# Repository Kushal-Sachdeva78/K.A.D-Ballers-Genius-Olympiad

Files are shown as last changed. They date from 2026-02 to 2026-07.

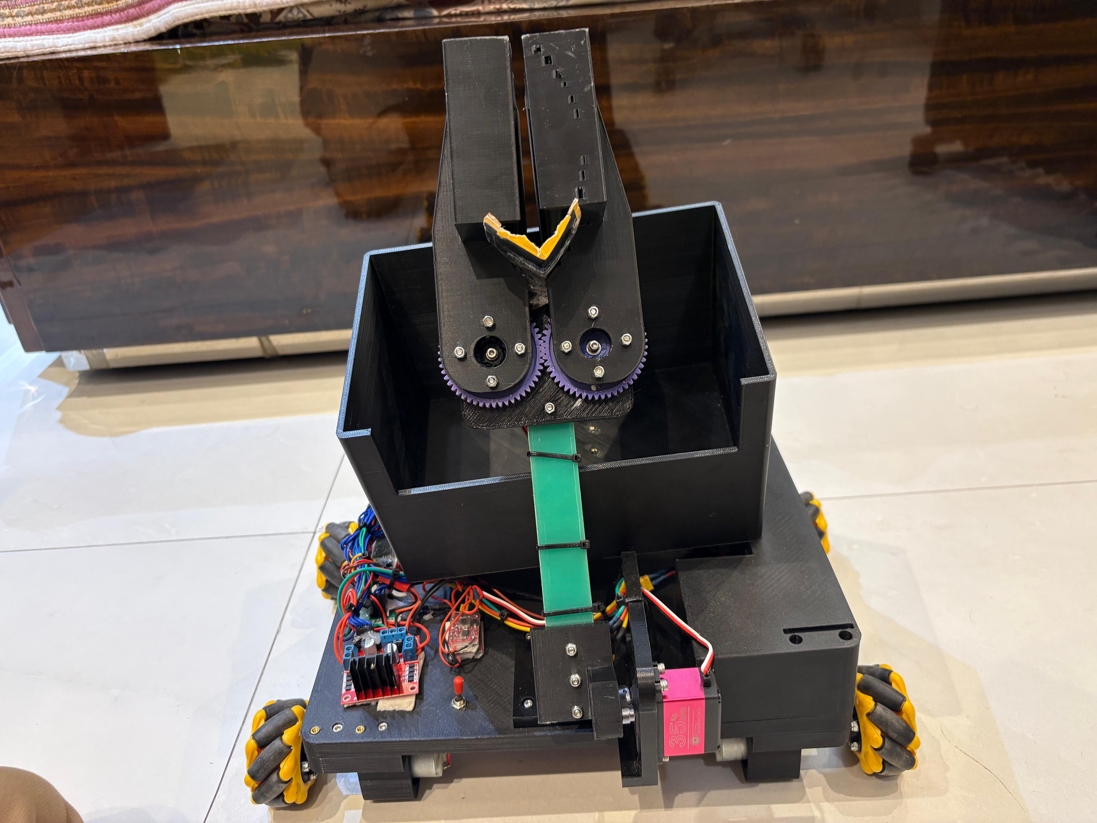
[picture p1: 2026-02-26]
Photos/Robot Image 1.jpeg

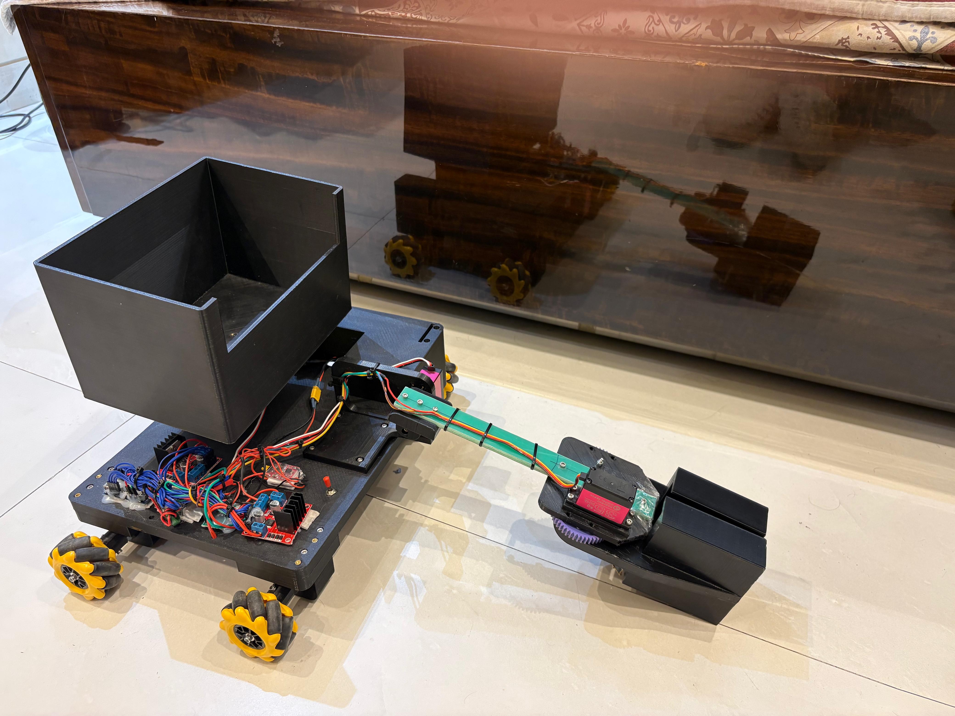
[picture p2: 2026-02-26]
Photos/Robot Image 8.jpeg

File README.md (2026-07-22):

# K.A.D Ballers: Genie Firefighter Robot

A tele-operated, four-wheel mecanum robot built by Team K.A.D Ballers for the GENIUS Olympiad robotics competition (GENIUS Robotics, Genie Firefighter 2026 game). The robot's chassis and mechanical parts are fully 3D printed in PETG, and it is driven over Bluetooth, using a three-servo manipulator to clear debris and place water gel cubes in the game's fire zone.





## Result

This project qualified as a GENIUS Olympiad finalist. The team did not attend the final round due to prior commitments.

## Team

- **Team name**: K.A.D Ballers
- **Members**: Kushal Sachdeva, Darsh Goel, Aaryan Singhania
- **School**: Vasant Valley School, Delhi, India

## Submission video

Official application video: [GENIUS Robotics_2026_KAD_Ballers on YouTube](https://youtu.be/bjkdxhQIA2E?si=Tjy7cpMIQIa94cFR)

## Robot overview

The Genie Firefighter game requires removing debris (tennis balls) from the safe zone into a debris bin, and collecting water gel cubes from the shared warehouse to place into the fire zone. Our robot handles both tasks with:

- **Mecanum drive**: four mecanum wheels for forward, backward, strafe, diagonal, and rotation movement. Each diagonal command drives exactly two of the four motors.
- **Three-servo manipulator**: an arm servo (smooth 1-degree stepped sweeps between down and up positions), a gripper servo (open/close), and a basket servo that flips to dump collected objects.
- **Bluetooth teleoperation**: an HC-05 module on a software serial port (9600 baud) receives single-character commands from a phone controller app.

## Hardware

| Component | Details |
| --- | --- |
| Microcontroller | Arduino Nano |
| Wireless | HC-05 Bluetooth module |
| Drive | 4x 12V 50 RPM DC motors with mecanum wheels |
| Motor drivers | 2x L298N dual H-bridge |
| Servos | 3x high-torque metal gear servos |
| Power | 12V battery with a buck converter to 5V for logic and servos |
| Chassis and parts | Fully 3D printed in PETG (SolidWorks sources and STL exports included) |

## Driver command map

| Movement | Key | Manipulator | Key |
| --- | --- | --- | --- |
| Forward / Backward | `F` / `B` | Arm up / down | `U` / `D` |
| Strafe left / right | `L` / `R` | Gripper open / close | `O` / `C` |
| Diagonals | `G` `H` `I` `J` | Basket load / unload | `M` / `N` |
| Rotate CW / CCW | `X` / `Y` | Stop | `S` |

## Repository contents

```
Code/mecanumwheelrobot/   # Arduino sketch: drive kinematics, servo control, Bluetooth command loop
3D Models/                # SolidWorks part files (.SLDPRT) with printable STL exports,
                          # plus the full assembled robot model
Photos/                   # Build, wiring, testing, and final robot photos
Docs/                     # Engineering books (Robot Design and Programming) as PDFs
```

## How to run

1. Upload `Code/mecanumwheelrobot/mecanumwheelrobot.ino` to an Arduino Nano.
2. Pair your phone with the HC-05 module.
3. Open a Bluetooth serial controller app and connect.
4. Drive and operate the manipulator with the mapped keys above.

## Related projects

Kushal and Darsh also compete as [Team VVS Ballers in RoboCupJunior Soccer](https://github.com/Kushal-Sachdeva78/VVS-Ballers-RoboCup), placing 9th at RoboCup 2026 in Incheon, South Korea.

## License

This project is licensed under the MIT License. See [LICENSE](LICENSE) for details.

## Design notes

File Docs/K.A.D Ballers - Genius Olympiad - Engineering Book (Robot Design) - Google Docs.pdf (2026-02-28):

# Engineering Book – Robot Design

## GENIUS Robotics — Genie Firefighter (2026)

Team Name: K.A.D Ballers
Team Members: Kushal Sachdeva, Darsh Goel, Aaryan Singhania School/Organization: Vasant Valley School, Delhi, India
GitHub: https://github.com/Kushal-Sachdeva78/K.A.D-Ballers-Genius-Olympiad-Robot

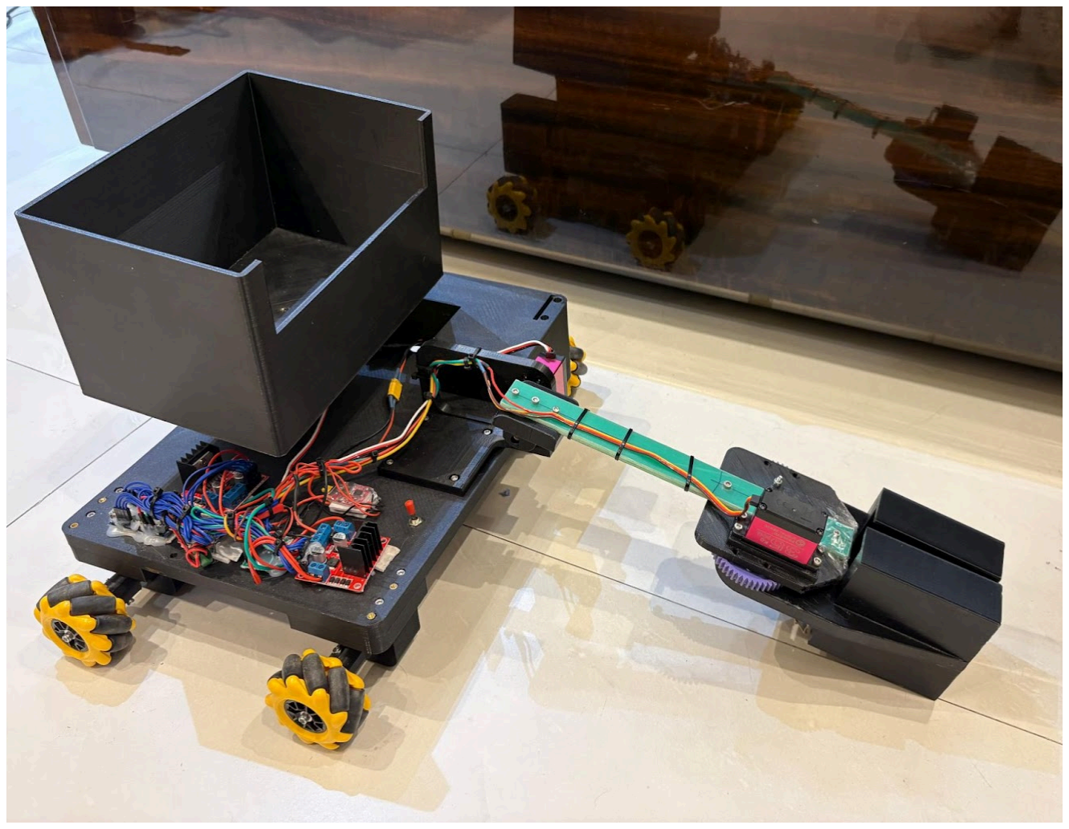
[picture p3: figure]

## 1. Executive Summary

Our Genie Firefighter robot is a tele-operated 4-mecanum drive platform designed to:

1. Clear debris (tennis balls) from the safe zone and deposit into the elevated debris bin
2. Collect water gel cubes from the shared warehouse and place them into the fire zone

The robot uses:

- 4× 12V 50 RPM DC motors for mecanum drive
- 3× metal gear 35 kg servos for arm lift, gripper open/close, and basket flip
- Arduino Nano as the main controller
- HC-05 Bluetooth module + phone app for wireless tele-op
- 2× L298N motor drivers to control the DC motors
- 12V battery + buck converter to power logic + servos

Manufacturing note: The entire robot chassis and mechanisms are 3D-printed in PETG (with metal fasteners/electronics installed).

## 2. Mission Breakdown & Constraints

### 2.1 Tasks

Task 1 (Debris):

- Collect 10 tennis balls from the safe zone
- Deposit them into the debris bin outside the field perimeter
- Safe zone must be cleared before Task 2 begins

Task 2 (Fire):

- Collect gel cubes (2.2”) from the shared warehouse
- Place/throw them into the fire zone
- Carry limit: max 5 cubes at a time
- Must not enter smoked damaged area; avoid touching buckets/houses

### 2.2 Constraints That Shaped Our Design

- Start size ≤ 20” × 20” × 20”
- Tele-op only, wireless communication only
- Onboard power only; ≤ 12V per power item
- Up to 8 DC motors allowed (we use 4)
- Accurate navigation near tape boundaries is essential (penalty avoidance)

## 3. Design Choices (Why this design)

### 3.1 Why Mecanum Drive

- Items are randomly placed → alignment speed matters
- Mecanum allows strafe + diagonal movement without turning
- Helps the driver make micro-adjustments near taped borders and around obstacles

### 3.2 Why Arm + Gripper + Basket Dump

- Tennis balls and gel cubes are different textures and shapes; a controlled grab is more reliable than pushing
- Arm + gripper gives repeatable pickup, basket provides storage, dump makes unloading faster

## 4. System Layout (Architecture)

### 4.1 Control Flow

Driver Phone (Bluetooth Serial App) → sends single character commands → HC-05 Bluetooth
→ Arduino Nano
→ outputs to:
- Motor Drivers (2× L298N) → 4 DC motors → mecanum wheels
- Servos → arm servo / gripper servo / basket servo

### 4.2 Power Distribution

- 12V battery → L298N boards → DC motors
- 12V battery → buck converter → regulated 5V rail → Arduino + HC-05 + servos
- Common ground shared across all modules for stability

## 5. Mechanical Design (Detailed)

### 5.1 Chassis & Packaging (PETG 3D Print)

Material: PETG (full robot printed)
Why PETG:
- Stronger and less brittle than PLA
- Better temperature resistance than PLA (helpful for motors/servo heat zones)
- Good layer adhesion for load-bearing parts

Chassis goals:

- Fit within starting size limits
- Keep center of gravity low (battery low, central)
- Protect electronics and wiring
- Provide rigid mounts for motors and servos (reduce flex)

Design features we included (recommended to mention during judging):

- Reinforced motor mounts (thicker walls + ribbing)
- Cable channels / tie points to prevent snagging
- Standoffs for electronics and buck converter
- Mount points that can be reprinted quickly if broken

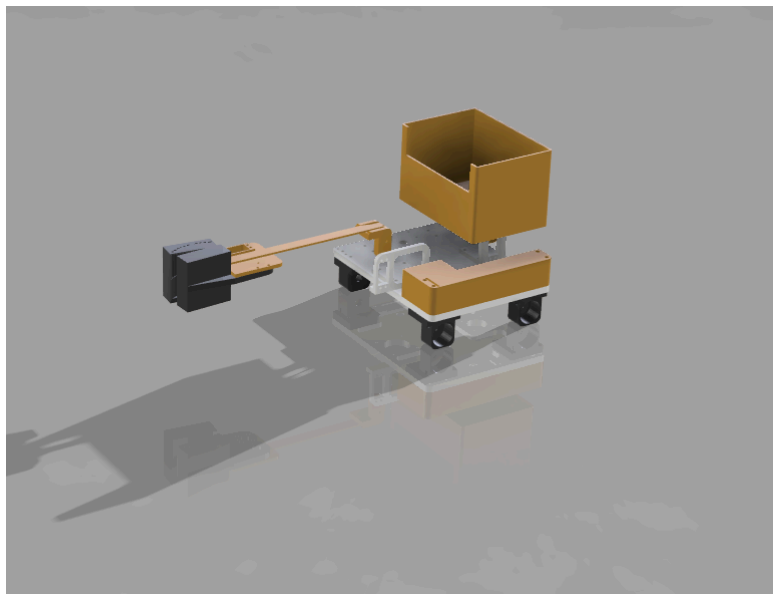
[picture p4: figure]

### 5.2 Drivetrain (4-Mecanum)

Components:

- 4 mecanum wheels
- 4× 12V 50 RPM DC motors
- 2× L298N drivers

Why it works for this game:

- Strafing reduces time spent turning
- Diagonals speed up alignment to scattered objects
- Rotation in place helps quick reorientation without overshooting taped boundaries

Build notes (PETG-specific):

- Wheel mounts printed with extra wall thickness
- Use washers/spacers to reduce wobble
- Ensure correct roller orientation (front-left/front-right must be mirrored)

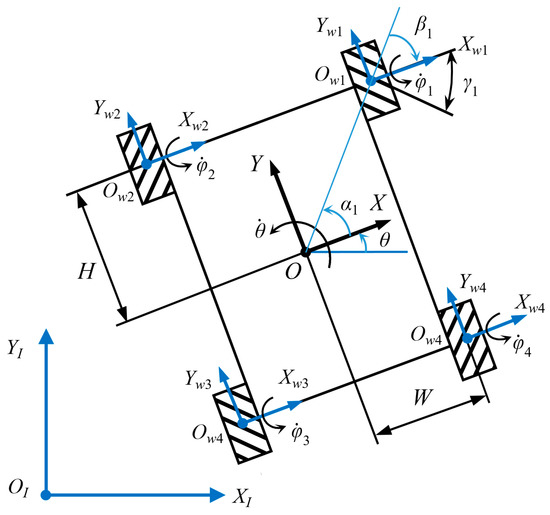
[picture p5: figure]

### 5.3 Arm Mechanism (Servo Lift)

Function: reach floor → lift to basket height Servo: 35 kg metal gear servo
Design requirements:
- Reach ground without pushing objects away
- Lift high enough to drop into basket
- Minimize flex (PETG parts reinforced)

Mechanical notes:

- Arm pivot printed thick + supported with ribs
- Servo horn mounting holes reinforced
- Endpoints tuned to avoid servo stalling at hard stops

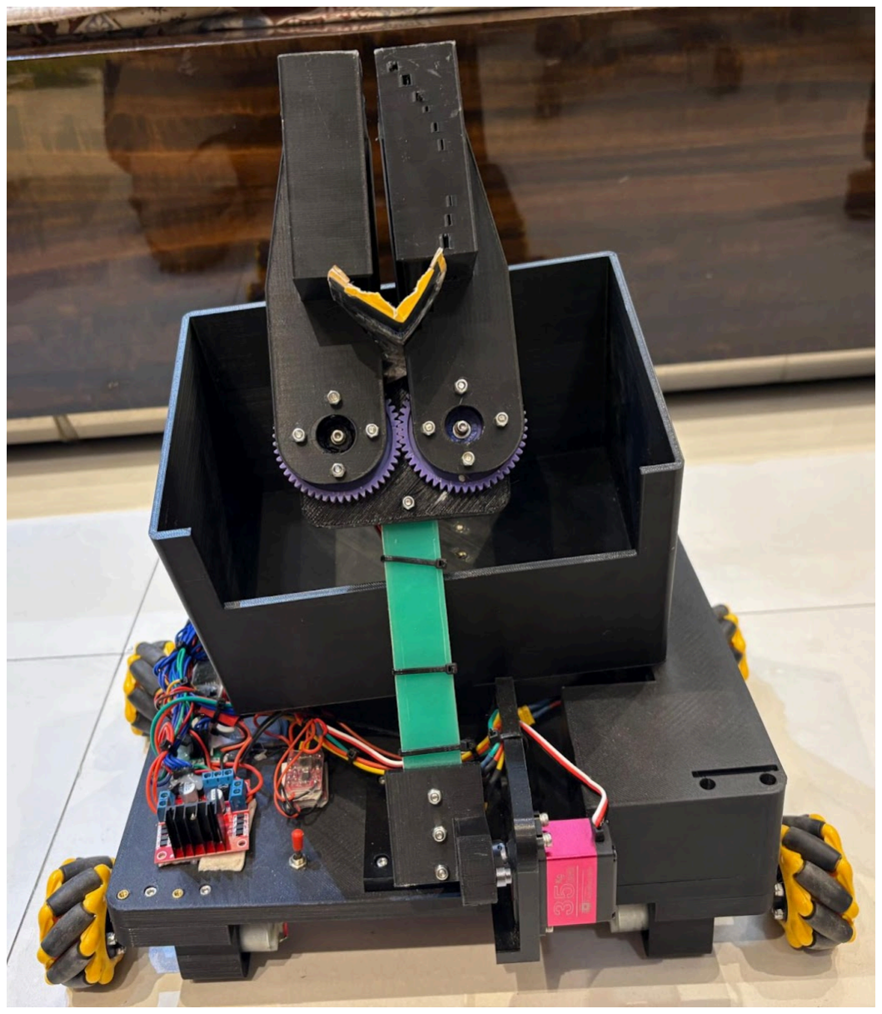
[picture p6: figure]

### 5.4 Gripper (Servo Open/Close)

Function: capture balls/cubes reliably
Servo: 35 kg metal gear servo
Design features:
- Jaw profile shaped to “cup” a tennis ball
- Closing angle tuned so gel cubes are held, not crushed
- Printed jaws reinforced at stress points (fillets/ribs)

Testing outcomes:

- Best grip happens when object is centered before closing
- Slow approach + stop command improves pickup reliability

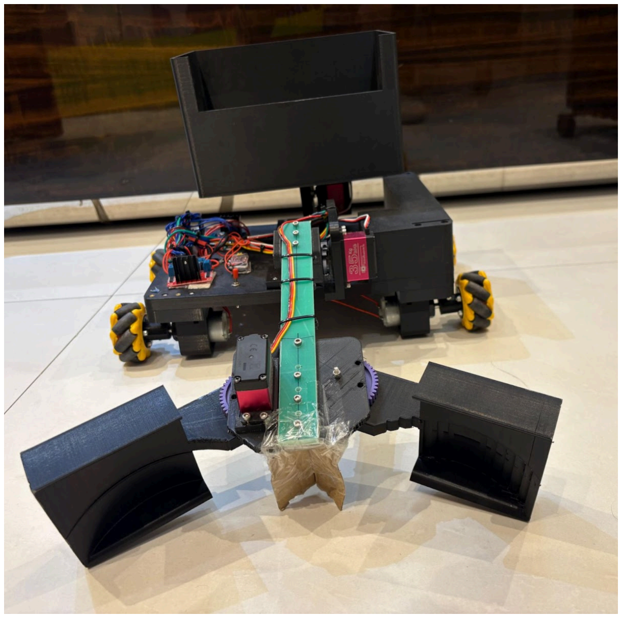
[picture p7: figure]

### 5.5 Basket / Holder + Flip Dump

Purpose:

- Store collected items (reduce trips)
- Dump quickly into debris bin / release cubes into fire zone

Mechanism:

- Basket mount hinged
- Servo moves between:
- LOAD position: holds items during driving
- UNLOAD position: flips to release

Key design constraint:

- Debris bin is elevated, so dumping angle and approach matter (future lift planned below)

## 6. Electronics Design

### 6.1 Parts Used

- Arduino Nano (main controller)
- HC-05 Bluetooth module
- 2× L298N motor driver boards
- 4× DC motors (12V, 50 RPM)
- 3× 35 kg metal gear servos
- 12V battery
- Buck converter (12V → 5V)
- Wiring, connectors, switch (recommended)

### 6.2 Electronics Layout Notes

- Keep buck converter close to Arduino/servo power distribution
- Route motor wires away from Bluetooth wires where possible
- Secure all connectors to withstand vibrations and arm motion

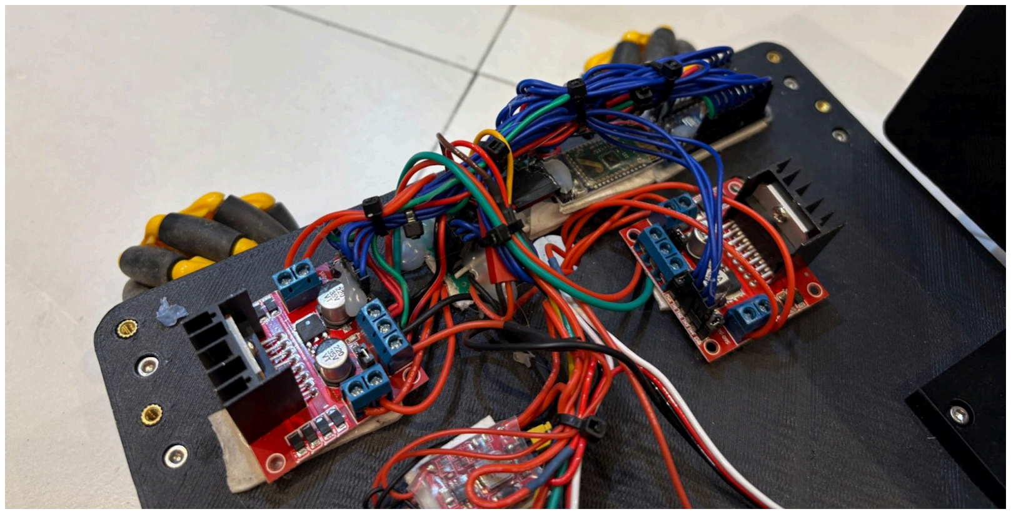
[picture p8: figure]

## 7. Coding Scheme

### 7.1 Control Method

A phone app sends single-character commands over Bluetooth to HC-05. Arduino Nano reads the character and triggers:

- mecanum movement patterns (forward/back/strafe/diagonal/rotate)
- servo position actions (arm, gripper, basket)

### 7.2 Driver Command Map (Summary)

Movement: F B L R S G H I J X Y
Servos: U/D arm, O/C gripper, M/N basket load/unload

## 8. Testing & Experiments (Development Evidence)

### 8.1 Drive Testing

- Straight driving (check drift)
- Strafing along tape line (precision)
- Rotation in place (control near boundaries)

Result: mecanum improved alignment speed significantly compared to turning-based drive.

### 8.2 Pickup Testing

- Tested tennis balls and cubes at different angles
- Tuned arm down position to prevent pushing objects away
- Tuned gripper close angle for secure hold without crushing cubes

### 8.3 Basket Testing

- Verified load position prevents spills while moving
- Verified unload position releases consistently into a target container

### 8.4 Power & Bluetooth Stability

- Tested simultaneous driving + servo movement for resets

- Verified stable control when phone is kept within close range
- Buck converter + common ground improved stability

## 9. Build Log (Recommended for Judges)

- Stage 1: CAD + first PETG chassis print (date, issues, fixes)
- Stage 2: drivetrain assembly and wheel orientation verification
- Stage 3: arm/gripper print iterations (strength improvements)
- Stage 4: electronics mounting + wiring organization
- Stage 5: integrated testing + driver training

## 10. Match Strategy

Task 1: strafe/diagonal align → arm down → grip → arm up → store → repeat → dump Task 2: warehouse entry → collect cubes (≤5) → return → place/throw into fire zone (avoid smoked zone)

Penalty prevention:

- slow down near buckets/tape
- stop before gripping
- avoid risky turns—use strafing instead

## 11. Future Implementations (Planned Upgrades)

### 11.1 Scissor Lift for Basket (Raise to Bin Height)

Problem: debris bin is elevated; dumping from low height can be inconsistent. Upgrade: add a scissor lift under the basket to raise it before unloading.

- Actuation options: lead screw + motor, linear actuator, or gear-driven lift
- Adds controlled vertical reach for consistent bin dumping

Expected benefit: faster scoring + fewer missed deposits.

### 11.2 Rubber-Band Rotating Intake (Fast Automatic Intake)

Problem: arm+gripper is reliable but slower for many items.
Upgrade: add a front rubber-band roller intake:
- two inward-spinning rollers pull balls/cubes automatically
- guides items into basket with less driver precision needed

Expected benefit: faster debris clear + faster cube collection + reduced driver workload.

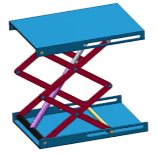
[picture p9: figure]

## 12. Bill of Materials (BOM)

Mechanical (3D Printed PETG)

- PETG filament (chassis, mounts, arm, gripper, basket, brackets)
- 4× mecanum wheels
- Fasteners: screws/nuts/washers (assorted)
- Hinges/pins for arm and basket pivots (printed or metal)

Electrical

- Arduino Nano
- HC-05 Bluetooth module
- 2× L298N motor drivers

- 4× 12V 50 RPM DC motors
- 3× 35 kg metal gear servos
- 12V battery pack
- Buck converter (12V → 5V)
- Wiring/connectors/switch/zip ties

## 13. GitHub Repository (Code + 3D Models + Photos)

All design files, code, and documentation are stored in our GitHub repository.

GitHub Repo Link:
https://github.com/Kushal-Sachdeva78/K.A.D-Ballers-Genius-Olympiad-Robot

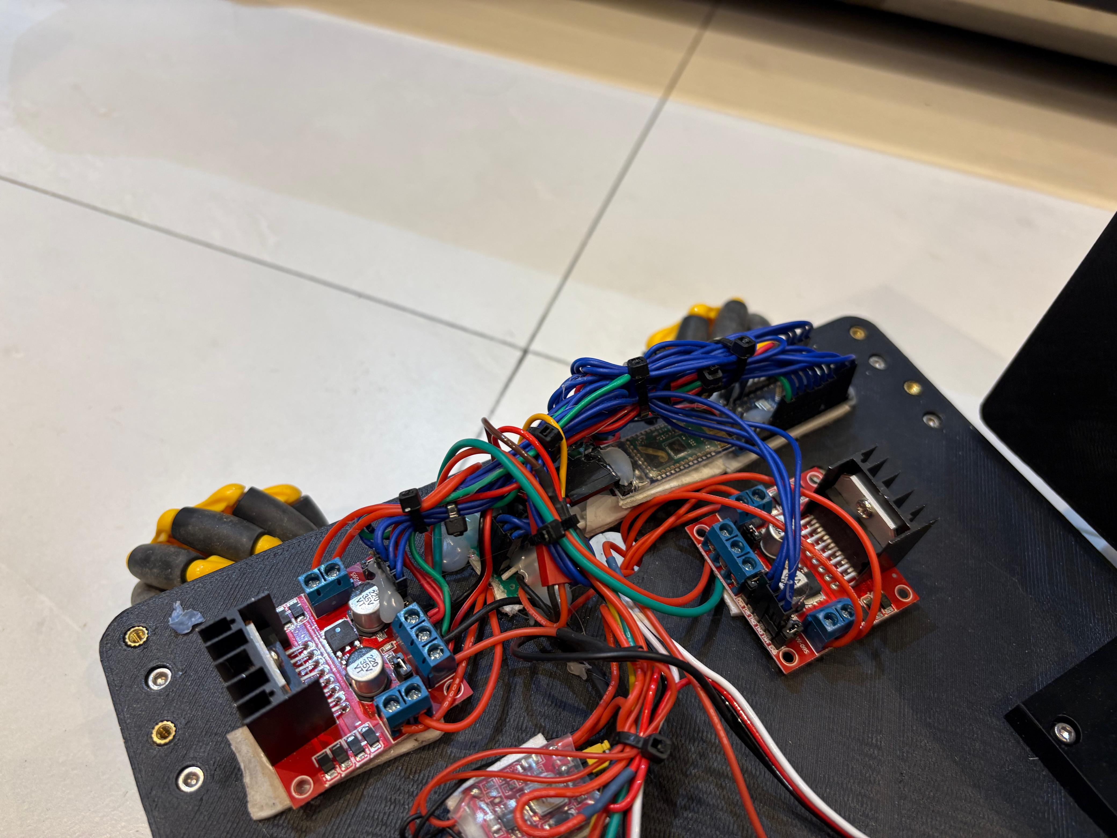
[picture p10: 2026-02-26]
Photos/Robot Image 4.jpeg

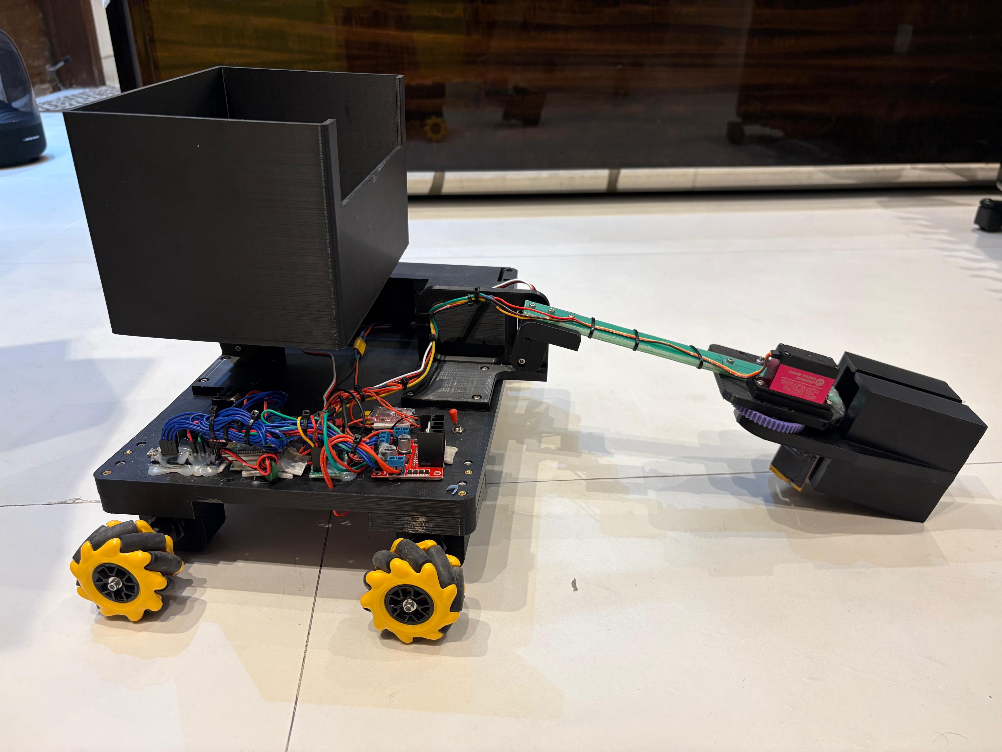
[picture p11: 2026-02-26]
Photos/Robot Image 7.jpeg

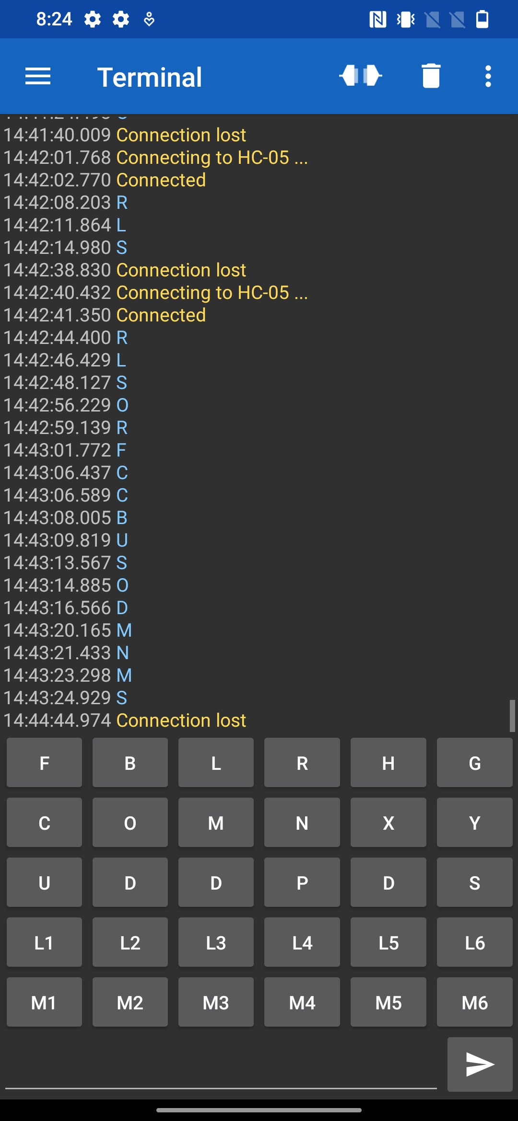
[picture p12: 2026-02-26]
Photos/Controller image.jpg

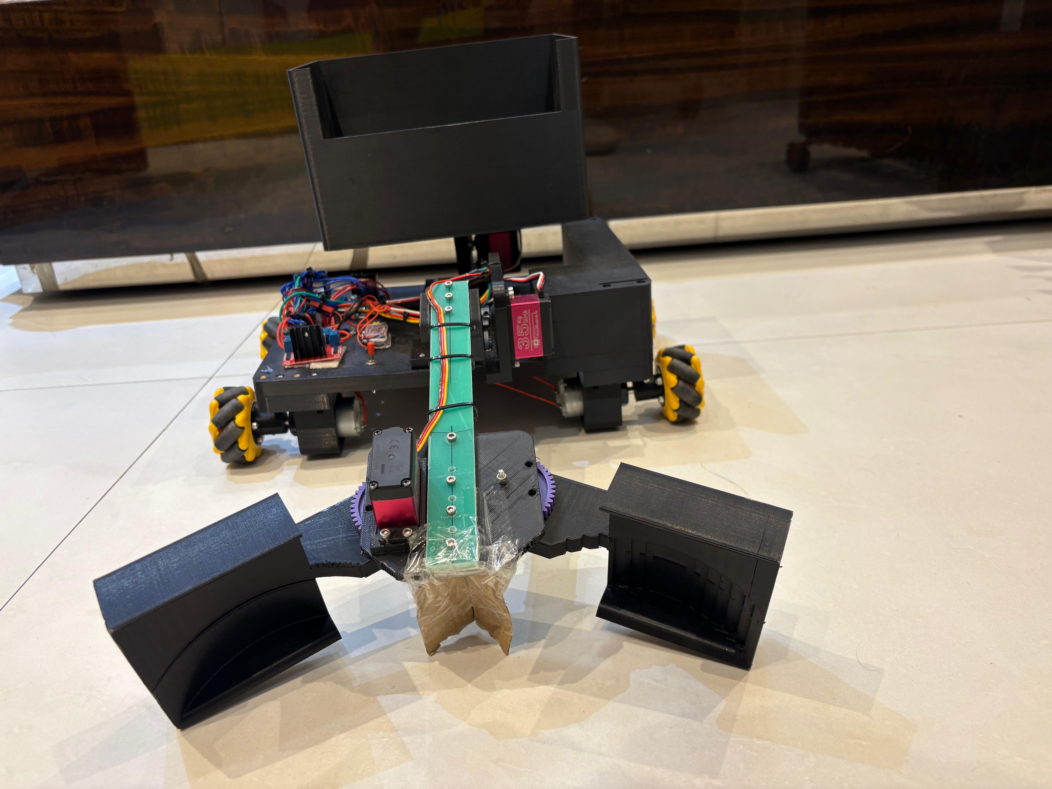
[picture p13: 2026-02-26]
Photos/Robot Image 6.jpeg

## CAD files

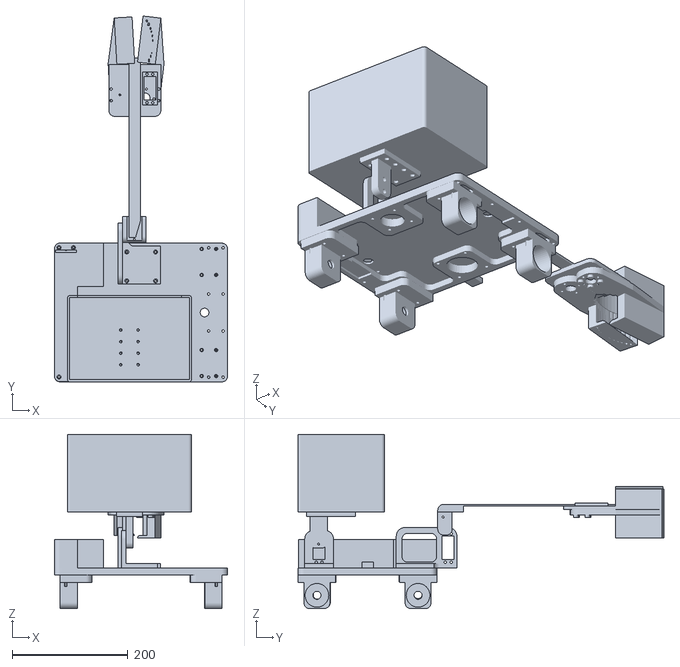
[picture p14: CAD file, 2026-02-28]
3D Models/Genius Olympiad Bot Model Final.stl
300.0 x 633.5 x 301.5

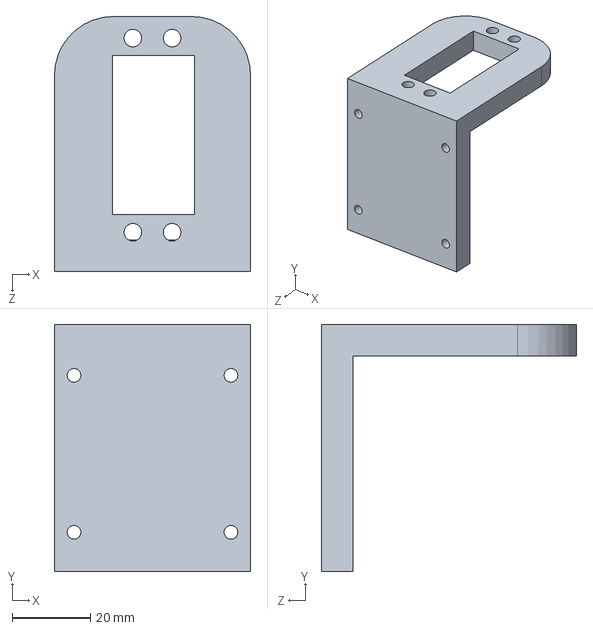
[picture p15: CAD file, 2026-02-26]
3D Models/baseservoholdballholdercase.SLDPRT
50.0 x 63.0 x 65.0 mm

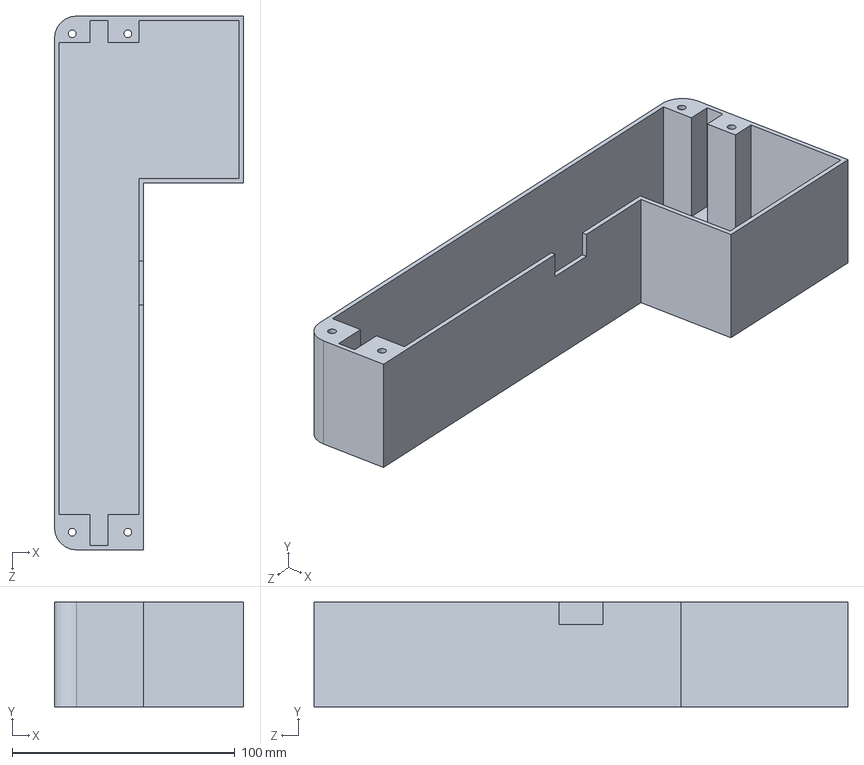
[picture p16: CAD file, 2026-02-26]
3D Models/sidecoverr.SLDPRT
85.0 x 47.0 x 240.0 mm

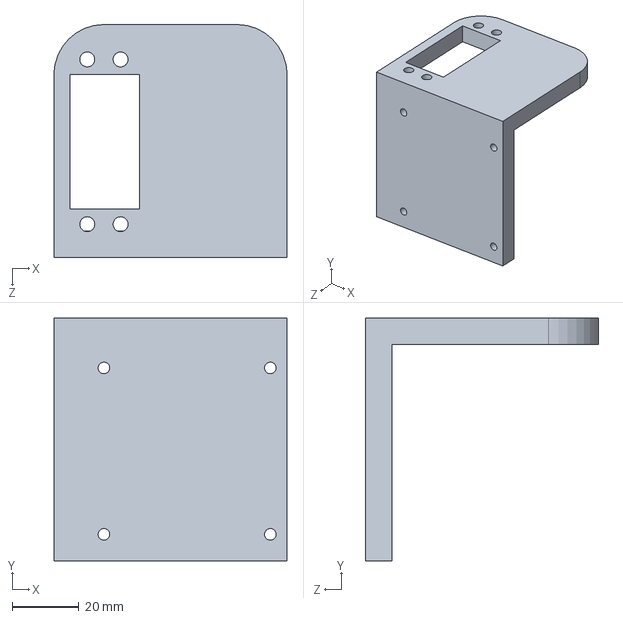
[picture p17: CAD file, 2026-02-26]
3D Models/baseservoholdgripper.SLDPRT
70.0 x 73.0 x 70.0 mm

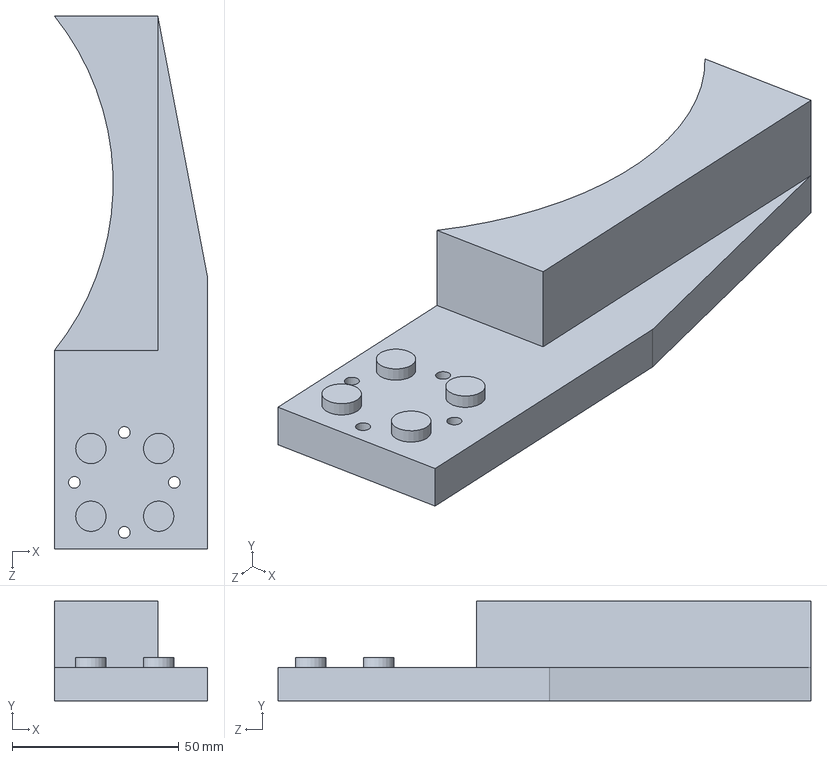
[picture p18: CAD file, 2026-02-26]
3D Models/grippermountother.SLDPRT
46.0 x 30.0 x 160.0 mm

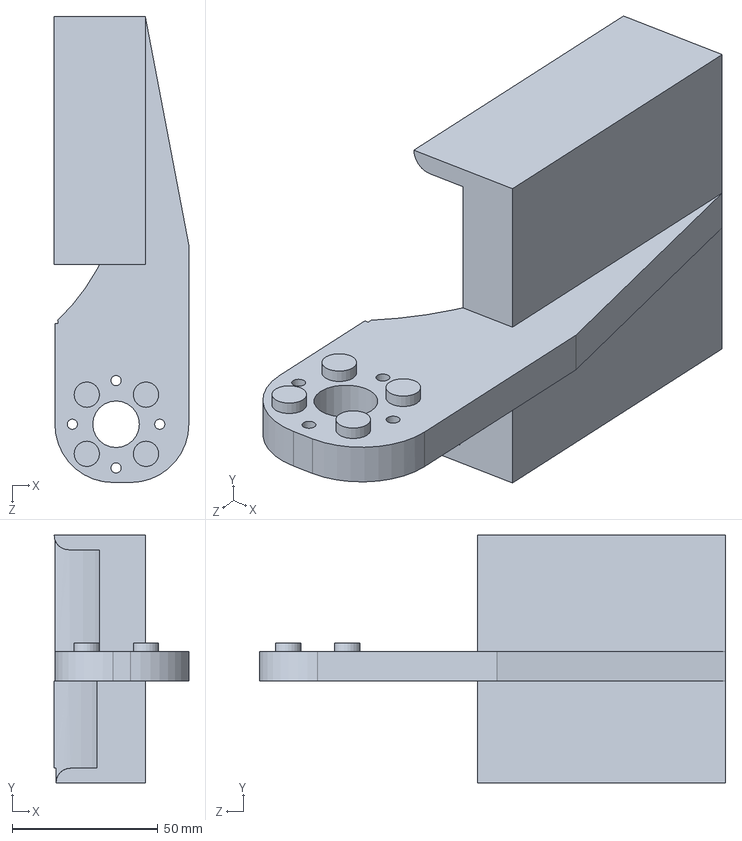
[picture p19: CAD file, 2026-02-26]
3D Models/grippermount.SLDPRT
46.3 x 85.0 x 160.0 mm

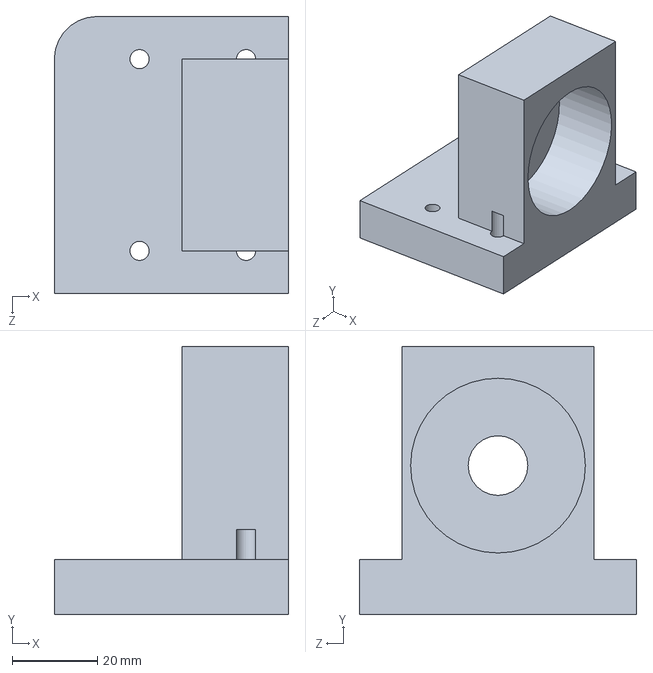
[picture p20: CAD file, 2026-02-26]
3D Models/motormountbase.SLDPRT
55.0 x 63.0 x 65.0 mm

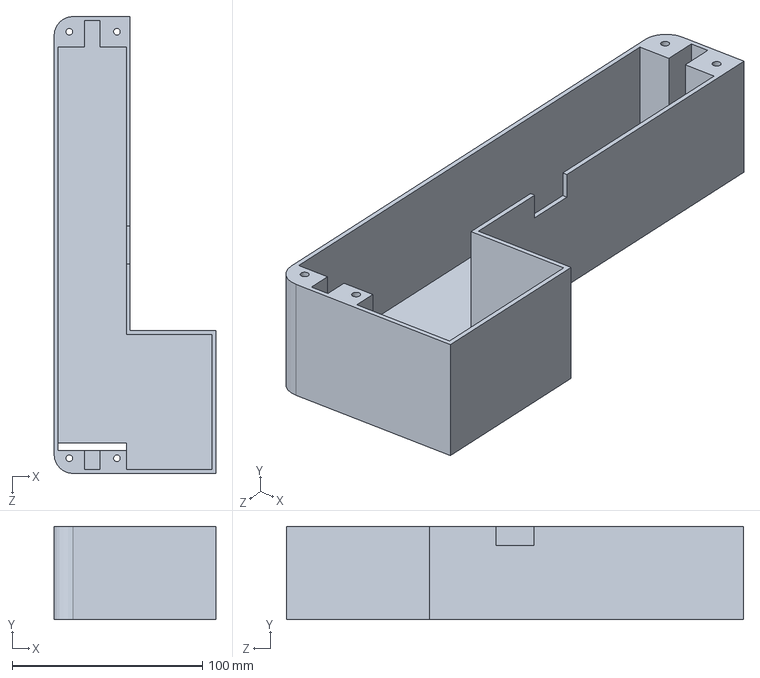
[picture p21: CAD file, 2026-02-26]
3D Models/sidecoverl.SLDPRT
85.0 x 49.0 x 240.0 mm

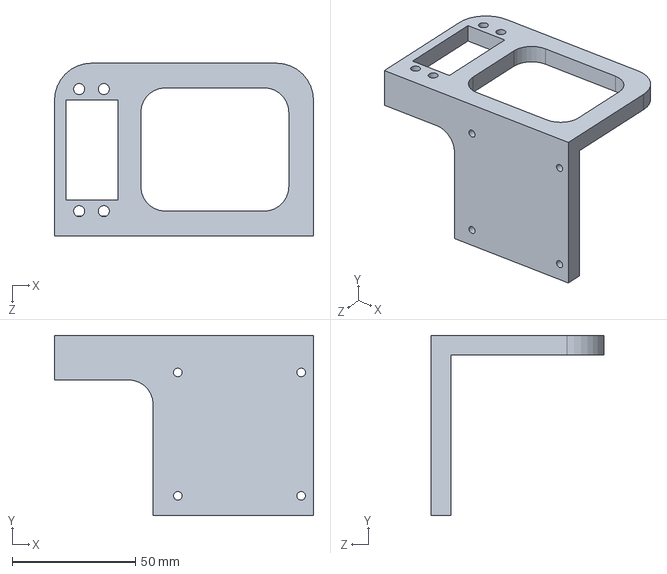
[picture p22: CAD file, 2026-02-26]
3D Models/baseservoholdgripperupgrade.SLDPRT
105.0 x 73.0 x 70.0 mm

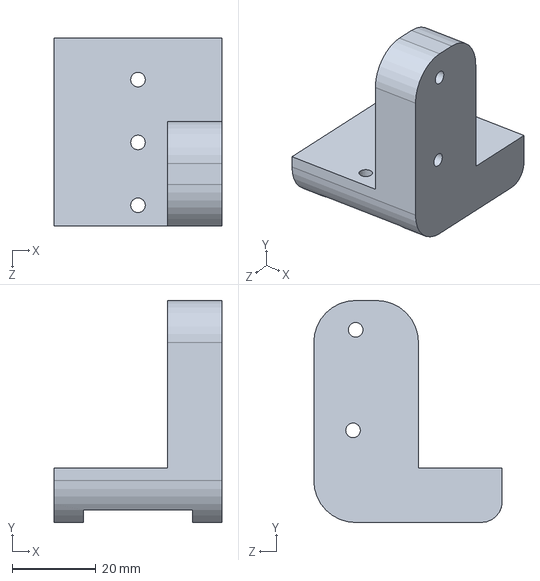
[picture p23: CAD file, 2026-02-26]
3D Models/gripperholderservomount.SLDPRT
40.0 x 53.0 x 45.0 mm

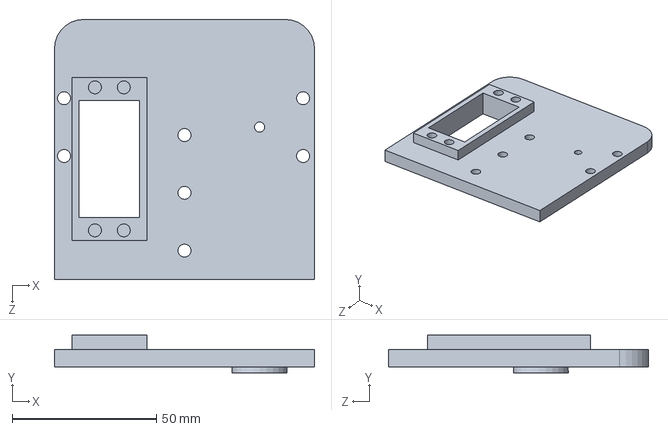
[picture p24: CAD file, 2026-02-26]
3D Models/grippermotorservo.SLDPRT
90.0 x 13.0 x 90.0 mm

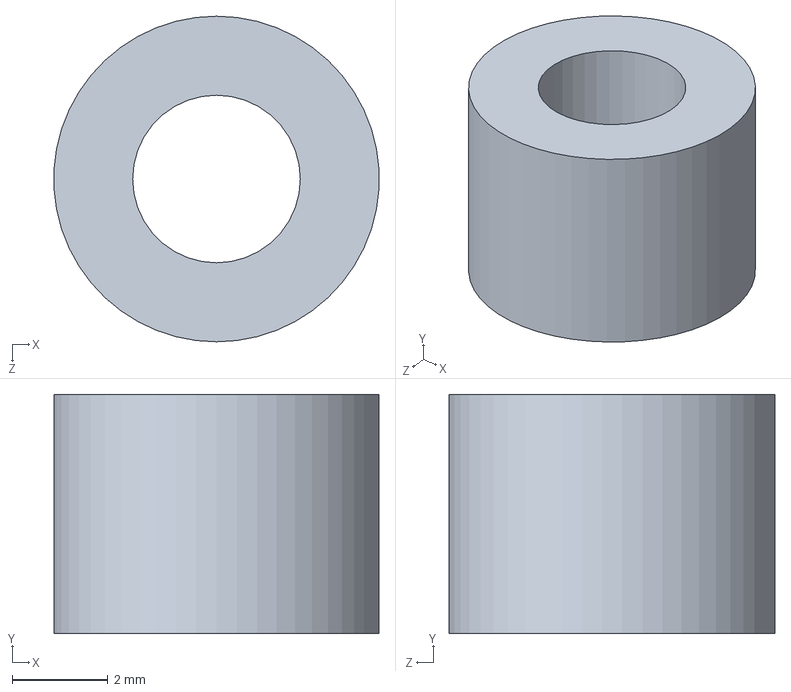
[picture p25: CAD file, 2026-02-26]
3D Models/rmotormountbasemisspart.SLDPRT
6.79 x 5.00 x 6.80 mm

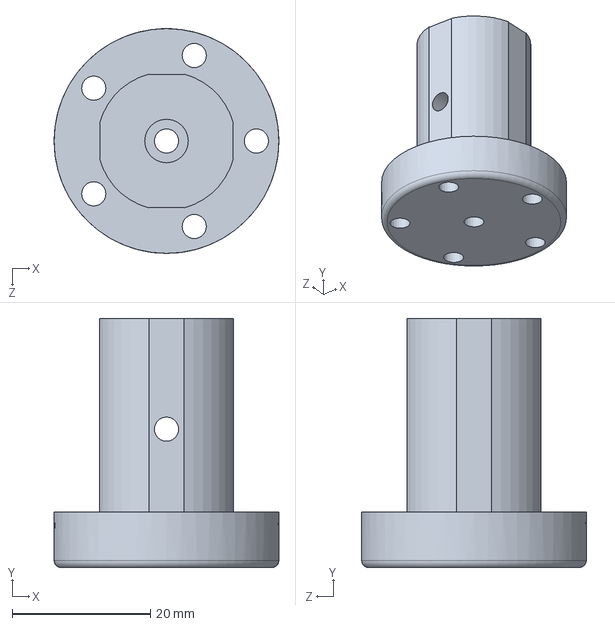
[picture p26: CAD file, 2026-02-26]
3D Models/wheelcircularaxle.SLDPRT
32.5 x 36.0 x 32.5 mm

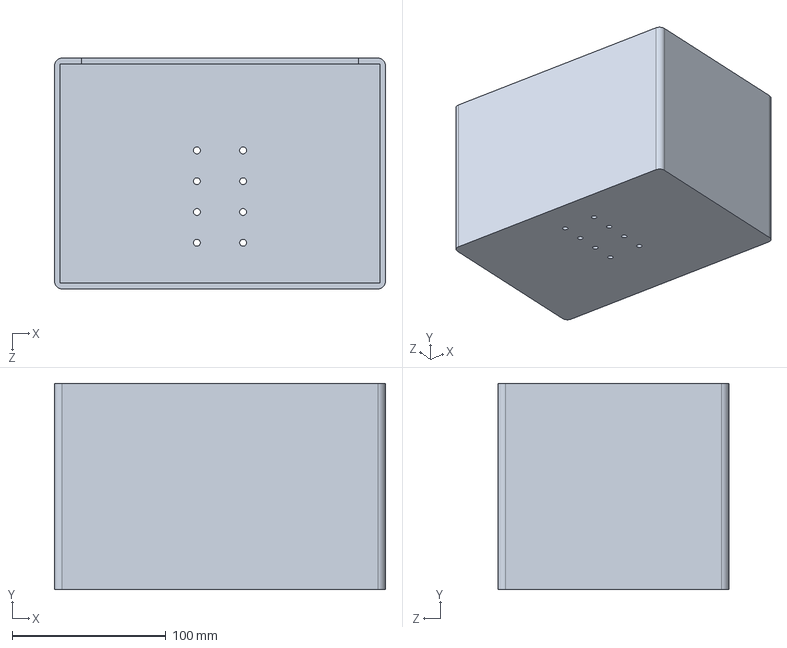
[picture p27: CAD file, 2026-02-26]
3D Models/ballholdercase.SLDPRT
215.0 x 134.0 x 150.0 mm

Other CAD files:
3D Models/grippermount2.SLDPRT
3D Models/lmotormountbase.SLDPRT
3D Models/robocarbase.SLDPRT
3D Models/servoholdballholdercase.SLDPRT
3D Models/ballholdercase.STL
3D Models/baseservoholdballholdercase.STL
3D Models/baseservoholdgripper.STL
3D Models/baseservoholdgripperupgrade.STL
3D Models/gripperholderservomount.STL
3D Models/grippermotorservo.STL
3D Models/grippermount.STL
3D Models/grippermount2.STL
3D Models/lmotormountbase.STL
3D Models/rmotormountbase.SLDPRT
3D Models/rmotormountbase.STL
3D Models/rmotormountbasemisspart.STL
3D Models/robocarbase.STL
3D Models/servoholdballholdercase.STL
3D Models/sidecoverl.STL
3D Models/sidecoverr.STL
3D Models/wheelcircularaxle.STL

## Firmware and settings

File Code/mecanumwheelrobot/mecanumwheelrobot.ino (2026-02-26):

#include <SoftwareSerial.h>
#include <Servo.h>

SoftwareSerial bluetooth(2, 3);

Servo ballHolderServo;
Servo ballArmServo;
Servo gripperServo;

#define FL_IN1 4
#define FL_IN2 5
#define FR_IN1 6
#define FR_IN2 7

#define BL_IN1 A0
#define BL_IN2 A1
#define BR_IN1 A2
#define BR_IN2 A3

const int HOLDER_LOAD   = 0;
const int HOLDER_UNLOAD = 70;

const int ARM_DOWN = 6;
const int ARM_UP   = 100;

const int GRIP_CLOSE = 0;
const int GRIP_OPEN  = 30;

int currentHolder = HOLDER_LOAD;
int currentArm    = ARM_DOWN;
int currentGrip   = GRIP_CLOSE;

void setup() {
  pinMode(FL_IN1, OUTPUT); pinMode(FL_IN2, OUTPUT);
  pinMode(FR_IN1, OUTPUT); pinMode(FR_IN2, OUTPUT);
  pinMode(BL_IN1, OUTPUT); pinMode(BL_IN2, OUTPUT);
  pinMode(BR_IN1, OUTPUT); pinMode(BR_IN2, OUTPUT);

  stopMotors();

  ballHolderServo.attach(9);
  ballArmServo.attach(10);
  gripperServo.attach(11);

  ballHolderServo.write(HOLDER_LOAD);
  ballArmServo.write(ARM_DOWN);
  gripperServo.write(GRIP_CLOSE);

  bluetooth.begin(9600);
  Serial.begin(9600);
  Serial.println("Mecanum Robot Ready - Directions Updated per Table");
  Serial.println("Movement: F B L R S G H I J X Y");
  Serial.println("Other:    C O U D M N");
}

void loop() {
  if (bluetooth.available()) {
    char command = bluetooth.read();
    Serial.print("Cmd: "); Serial.println(command);

    switch (command) {
      case 'F': moveForward();   break;
      case 'B': moveBackward();  break;
      case 'L': strafeLeft();    break;
      case 'R': strafeRight();   break;
      case 'S': stopMotors();    break;

      case 'G': diagonalFrontLeft();  break; 
      case 'H': diagonalFrontRight(); break; 
      case 'I': diagonalBackLeft();   break; 
      case 'J': diagonalBackRight();  break; 

      case 'X': rotateClockwise();        break;
      case 'Y': rotateCounterClockwise(); break;

      case 'C': setGripper(GRIP_CLOSE); break;
      case 'O': setGripper(GRIP_OPEN);  break;

      case 'U': moveArmTo(ARM_UP);   break;
      case 'D': moveArmTo(ARM_DOWN); break;

      case 'M': setBallHolder(HOLDER_LOAD);   break;
      case 'N': setBallHolder(HOLDER_UNLOAD); break;
    }
  }
}

void moveForward() {
  digitalWrite(FL_IN1, HIGH); digitalWrite(FL_IN2, LOW);
  digitalWrite(FR_IN1, HIGH); digitalWrite(FR_IN2, LOW);
  digitalWrite(BL_IN1, HIGH); digitalWrite(BL_IN2, LOW);
  digitalWrite(BR_IN1, HIGH); digitalWrite(BR_IN2, LOW);
}

void moveBackward() {
  digitalWrite(FL_IN1, LOW);  digitalWrite(FL_IN2, HIGH);
  digitalWrite(FR_IN1, LOW);  digitalWrite(FR_IN2, HIGH);
  digitalWrite(BL_IN1, LOW);  digitalWrite(BL_IN2, HIGH);
  digitalWrite(BR_IN1, LOW);  digitalWrite(BR_IN2, HIGH);
}

void strafeLeft() {
  digitalWrite(FL_IN1, LOW);  digitalWrite(FL_IN2, HIGH);
  digitalWrite(FR_IN1, HIGH); digitalWrite(FR_IN2, LOW);
  digitalWrite(BL_IN1, HIGH); digitalWrite(BL_IN2, LOW);
  digitalWrite(BR_IN1, LOW);  digitalWrite(BR_IN2, HIGH);
}

void strafeRight() {
  digitalWrite(FL_IN1, HIGH); digitalWrite(FL_IN2, LOW);
  digitalWrite(FR_IN1, LOW);  digitalWrite(FR_IN2, HIGH);
  digitalWrite(BL_IN1, LOW);  digitalWrite(BL_IN2, HIGH);
  digitalWrite(BR_IN1, HIGH); digitalWrite(BR_IN2, LOW);
}

void diagonalFrontLeft() {
  digitalWrite(FL_IN1, HIGH); digitalWrite(FL_IN2, LOW);
  digitalWrite(FR_IN1, LOW);  digitalWrite(FR_IN2, LOW);
  digitalWrite(BL_IN1, LOW);  digitalWrite(BL_IN2, LOW);
  digitalWrite(BR_IN1, HIGH); digitalWrite(BR_IN2, LOW);
}

void diagonalFrontRight() {
  digitalWrite(FL_IN1, LOW);  digitalWrite(FL_IN2, LOW);
  digitalWrite(FR_IN1, HIGH); digitalWrite(FR_IN2, LOW);
  digitalWrite(BL_IN1, HIGH); digitalWrite(BL_IN2, LOW);
  digitalWrite(BR_IN1, LOW);  digitalWrite(BR_IN2, LOW);
}

void diagonalBackLeft() {
  digitalWrite(FL_IN1, LOW);  digitalWrite(FL_IN2, LOW);
  digitalWrite(FR_IN1, LOW);  digitalWrite(FR_IN2, LOW);
  digitalWrite(BL_IN1, HIGH); digitalWrite(BL_IN2, LOW);
  digitalWrite(BR_IN1, LOW);  digitalWrite(BR_IN2, HIGH);
}

void diagonalBackRight() {
  digitalWrite(FL_IN1, HIGH); digitalWrite(FL_IN2, LOW);
  digitalWrite(FR_IN1, LOW);  digitalWrite(FR_IN2, HIGH);
  digitalWrite(BL_IN1, LOW);  digitalWrite(BL_IN2, LOW);
  digitalWrite(BR_IN1, LOW);  digitalWrite(BR_IN2, LOW);
}

void rotateClockwise() {
  digitalWrite(FL_IN1, HIGH); digitalWrite(FL_IN2, LOW);
  digitalWrite(FR_IN1, LOW);  digitalWrite(FR_IN2, HIGH);
  digitalWrite(BL_IN1, HIGH); digitalWrite(BL_IN2, LOW);
  digitalWrite(BR_IN1, LOW);  digitalWrite(BR_IN2, HIGH);
}

void rotateCounterClockwise() {
  digitalWrite(FL_IN1, LOW);  digitalWrite(FL_IN2, HIGH);
  digitalWrite(FR_IN1, HIGH); digitalWrite(FR_IN2, LOW);
  digitalWrite(BL_IN1, LOW);  digitalWrite(BL_IN2, HIGH);
  digitalWrite(BR_IN1, HIGH); digitalWrite(BR_IN2, LOW);
}

void stopMotors() {
  digitalWrite(FL_IN1, LOW); digitalWrite(FL_IN2, LOW);
  digitalWrite(FR_IN1, LOW); digitalWrite(FR_IN2, LOW);
  digitalWrite(BL_IN1, LOW); digitalWrite(BL_IN2, LOW);
  digitalWrite(BR_IN1, LOW); digitalWrite(BR_IN2, LOW);
}

void setBallHolder(int target) {
  if (target == currentHolder) return;
  ballHolderServo.write(target);
  currentHolder = target;
  delay(300);
}

void setGripper(int target) {
  if (target == currentGrip) return;
  gripperServo.write(target);
  currentGrip = target;
  delay(300);
}

void moveArmTo(int target) {
  if (target == currentArm) return;

  int start = currentArm;
  int step = (target > start) ? 1 : -1;
  int delayMs = 30;

  for (int pos = start; pos != target; pos += step) {
    ballArmServo.write(pos);
    delay(delayMs);
  }
  ballArmServo.write(target);
  currentArm = target;
}

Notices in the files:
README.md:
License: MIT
